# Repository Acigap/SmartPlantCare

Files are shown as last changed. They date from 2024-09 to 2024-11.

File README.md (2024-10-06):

# SmartPlantCare

**SmartPlantCare** is an automated plant watering system powered by ESP32 with a web interface for configuration and real-time monitoring, soil moisture sensors, SD card logging, and optional remote control through Blynk. The system uses **ESP32 T-Display-S3** for displaying data and **LILYGO® T-Display-S3 TF Shield** for SD card handling.

## Features
- Automatic irrigation based on soil moisture levels
- Hourly data logging to an SD card
- Real-time data display on **ESP32 T-Display-S3**
- Web interface for configuration and monitoring at `http://esp32sd.local`
- Remote control via Blynk app (optional)

## Components
- **ESP32 T-Display-S3**
- **LILYGO® T-Display-S3 TF Shield** (for SD card functionality)
- Soil Moisture Sensor
- Water Pump
- Relay Module
- Jumper wires
- Power supply (5V)
- Blynk App (optional)

## Hardware Setup

### 1. ESP32 T-Display-S3
- The **ESP32 T-Display-S3** includes a built-in display for real-time data such as soil moisture, watering status, and date/time.

### 2. LILYGO® T-Display-S3 TF Shield (SD Card Module)
- This shield is used for logging data to an SD card.
- **Wiring**:
  - MISO to GPIO 19
  - MOSI to GPIO 23
  - SCK to GPIO 18
  - CS to GPIO 5

### 3. Soil Moisture Sensor
- VCC to 3.3V (or 5V depending on the sensor)
- GND to GND
- Data to ESP32 analog pin (e.g., A0)

### 4. Water Pump & Relay Module
- Relay VCC to 5V
- Relay GND to GND
- IN to GPIO pin (e.g., GPIO 13)
- Water pump connected to relay (NO, COM)

## Software Setup

### 1. Install Required Libraries
- Open Arduino IDE and install the following libraries:
  - `TFT_eSPI` (for the **ESP32 T-Display-S3** screen)
  - `Blynk` (for remote control via Blynk)
  - `SD` (for handling SD card operations)
  - `ESPAsyncWebServer` (for the web interface)
  - `AsyncTCP` (for handling asynchronous web requests)

### 2. Clone the Repository
- Clone the repository and open `SmartPlantCare.ino` in Arduino IDE:
  ```bash
  git clone https://github.com/Acigap/SmartPlantCare.git
  ```

### 3. Web Interface Configuration
- The system includes a web interface for real-time monitoring and configuration. It allows you to:
  - View current soil moisture levels
  - Manually start or stop the water pump
  - Adjust soil moisture thresholds for automatic watering

**Web Interface Setup**:
- The ESP32 hosts a web server accessible at `http://esp32sd.local`.
- Ensure your ESP32 is connected to the same Wi-Fi network. Open a web browser and type `http://esp32sd.local` to access the web interface.

### 4. Blynk Setup (Optional)
- Install the Blynk app from the app store.
- Create a new project in the Blynk app and configure it to display soil moisture levels and control the water pump.

### 5. Upload the Code
- In Arduino IDE, select the correct board (`ESP32 T-Display-S3`) and port.
- Upload the code to your ESP32 board.

### 6. SD Card Logging
- The system logs data to a CSV file on the SD card every hour.
- The CSV log includes a timestamp, soil moisture level, and any watering actions.

### 7. Libraries Used

This project utilizes the following libraries, which can be found in the [T-Display-S3 GitHub repository](https://github.com/Xinyuan-LilyGO/T-Display-S3):

- **TFT_eSPI**: For controlling the TFT display on the ESP32 T-Display-S3.
- **Blynk**: For remote control and monitoring via the Blynk application.
- **SD**: For handling SD card operations to log data.
- **ESPAsyncWebServer**: To create a web server for real-time monitoring and configuration.
- **AsyncTCP**: To handle asynchronous TCP connections for the web server.

Ensure you install these libraries through the Arduino Library Manager or download them from their respective repositories.

## Usage

1. **Initial Setup**:
   - Place the soil moisture sensor in the plant’s soil.
   - Connect the water pump and ensure the SD card is inserted.

2. **Display**:
   - Real-time data, such as soil moisture percentage, system status, and last watering time, is displayed on the **ESP32 T-Display-S3**.

3. **Web Interface**:
   - Access the web interface by typing `http://esp32sd.local` into a browser.
   - Use the web interface to configure settings, monitor soil moisture levels, and manually control the water pump.

4. **Blynk** (optional):
   - Use the Blynk app to remotely monitor and control the system.

5. **SD Card**:
   - The system logs data on the SD card in CSV format.
   - You can download the logs from the web interface.

## Wiring Diagram
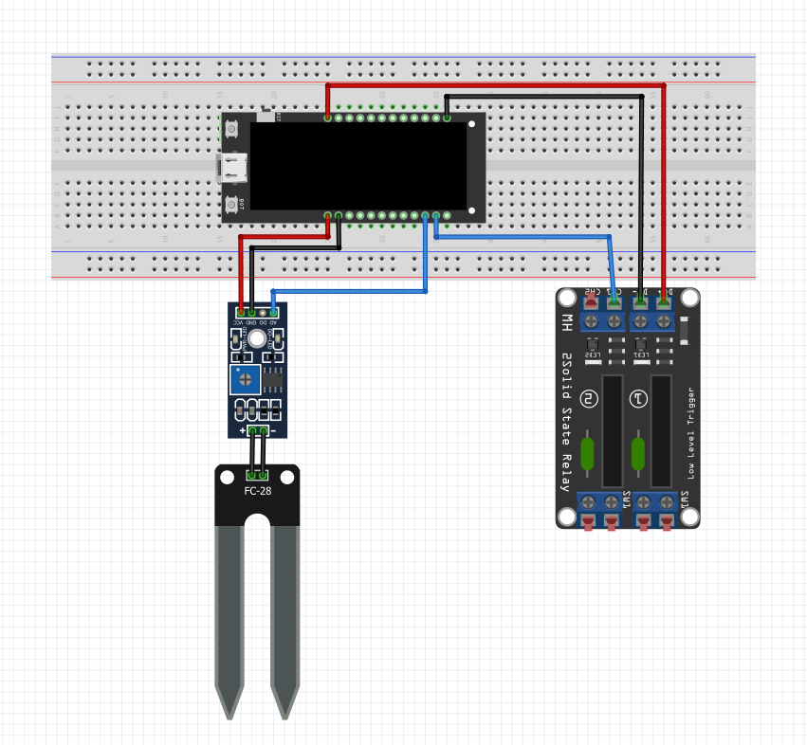
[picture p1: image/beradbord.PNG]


## Image 
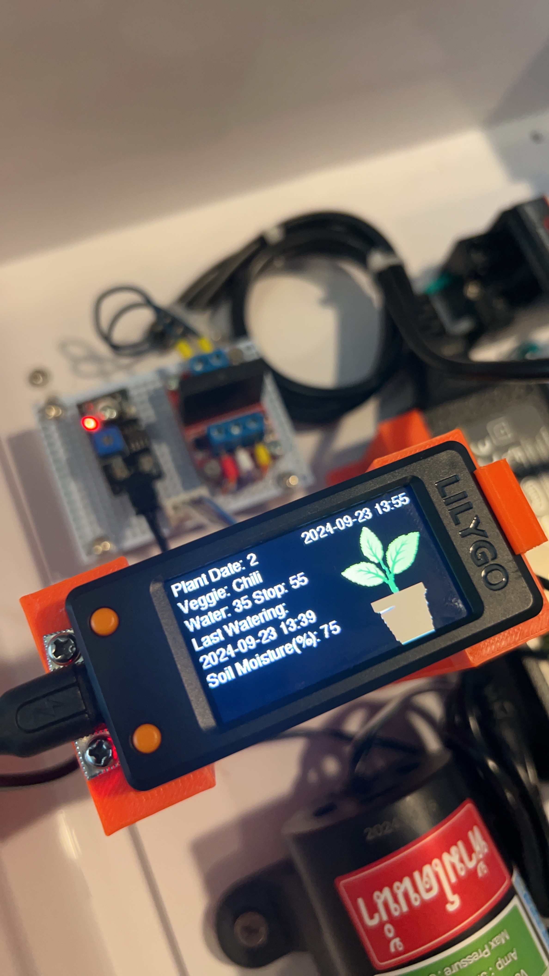
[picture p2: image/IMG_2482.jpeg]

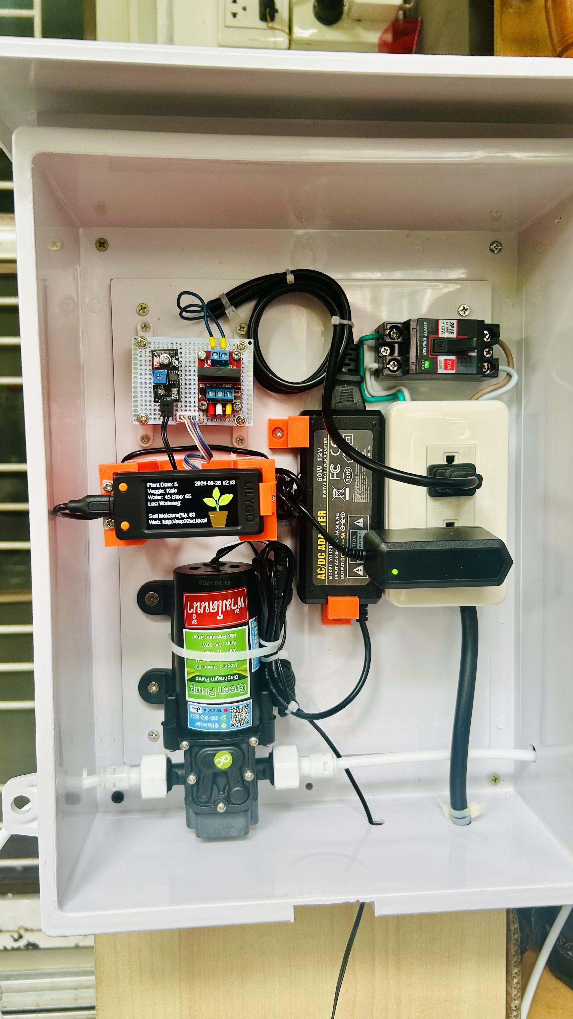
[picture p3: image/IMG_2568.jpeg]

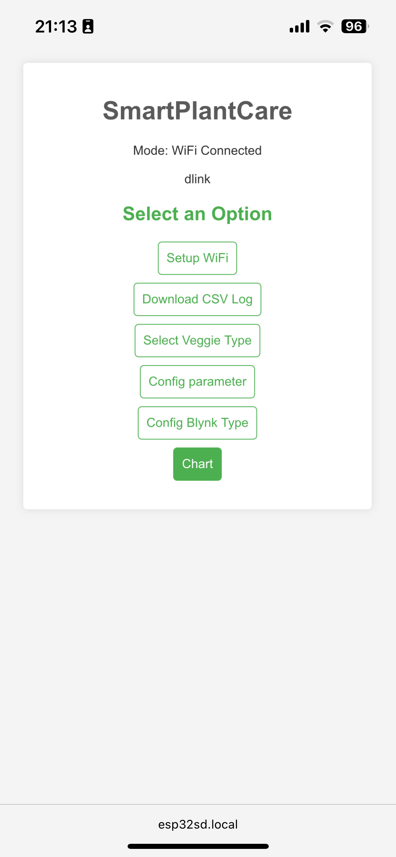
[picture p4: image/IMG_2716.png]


## Troubleshooting

- **Display not working**: Ensure the `TFT_eSPI` library is properly configured for **ESP32 T-Display-S3**.
- **Web interface not accessible**: Verify that the ESP32 is connected to Wi-Fi and try pinging `esp32sd.local` to check connectivity.
- **SD card issues**: Ensure the SD card is properly inserted and formatted correctly.

## License
This project is licensed under the MIT License.

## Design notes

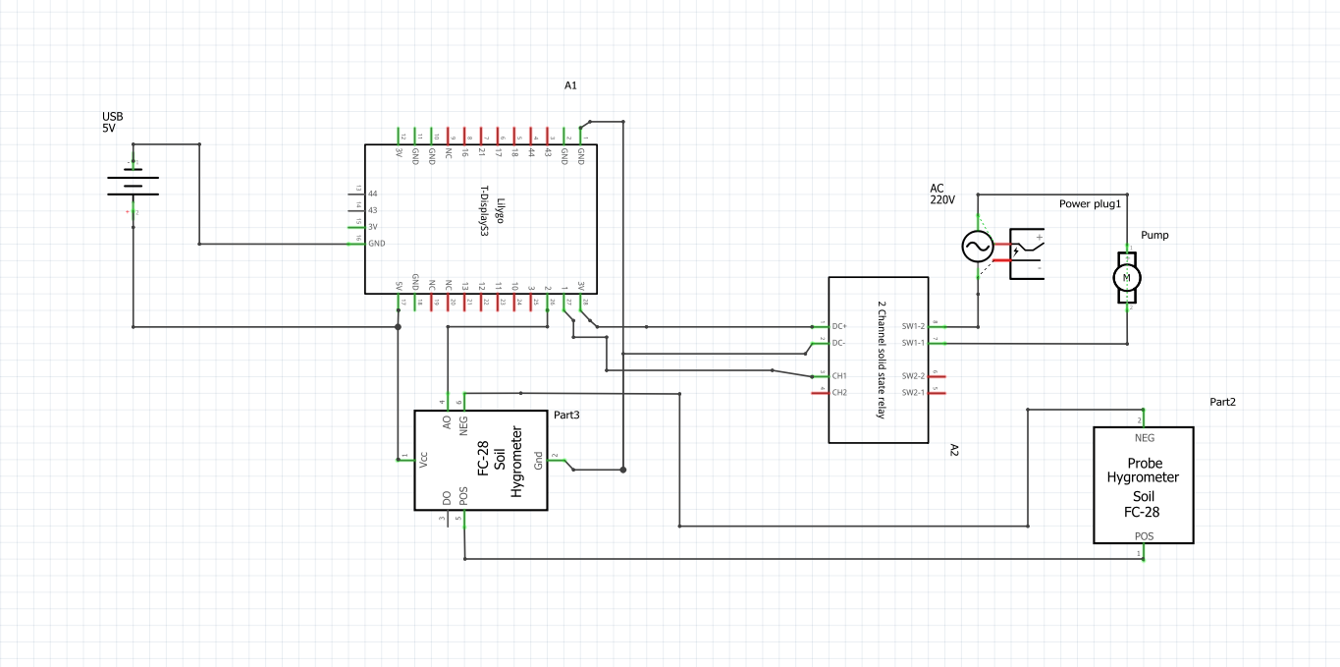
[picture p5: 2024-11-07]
image/schematicNoSD.PNG

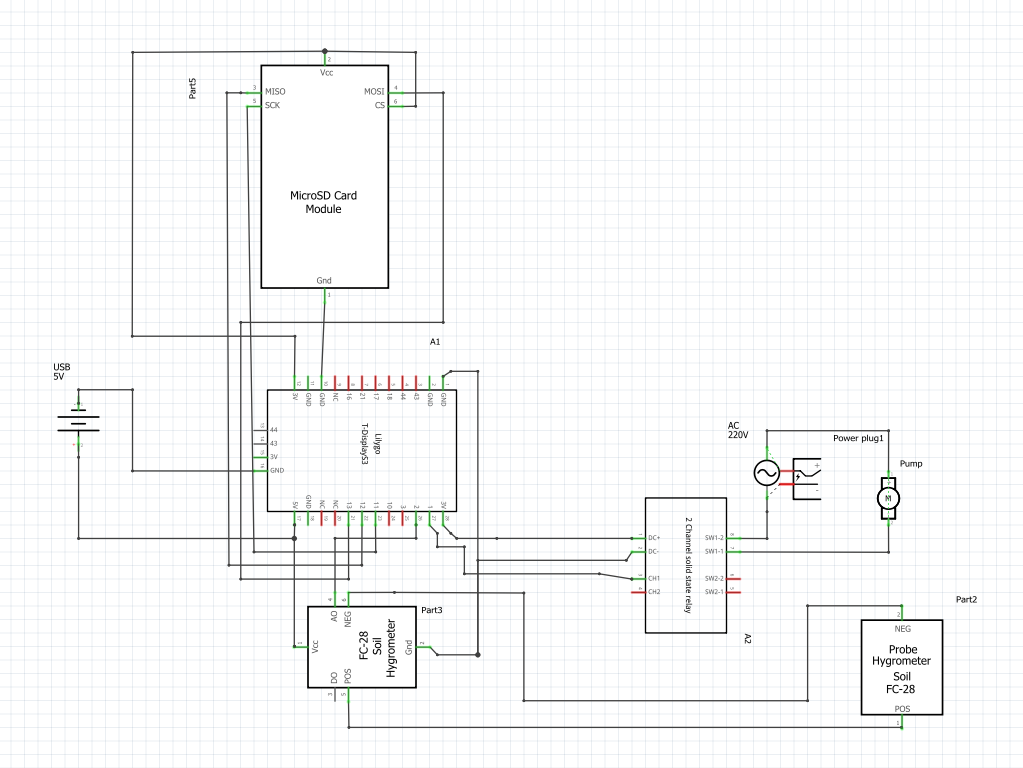
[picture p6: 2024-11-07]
image/schematic.PNG

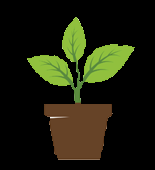
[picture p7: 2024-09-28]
image/plant.png

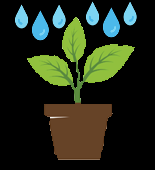
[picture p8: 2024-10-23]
image/watering.png

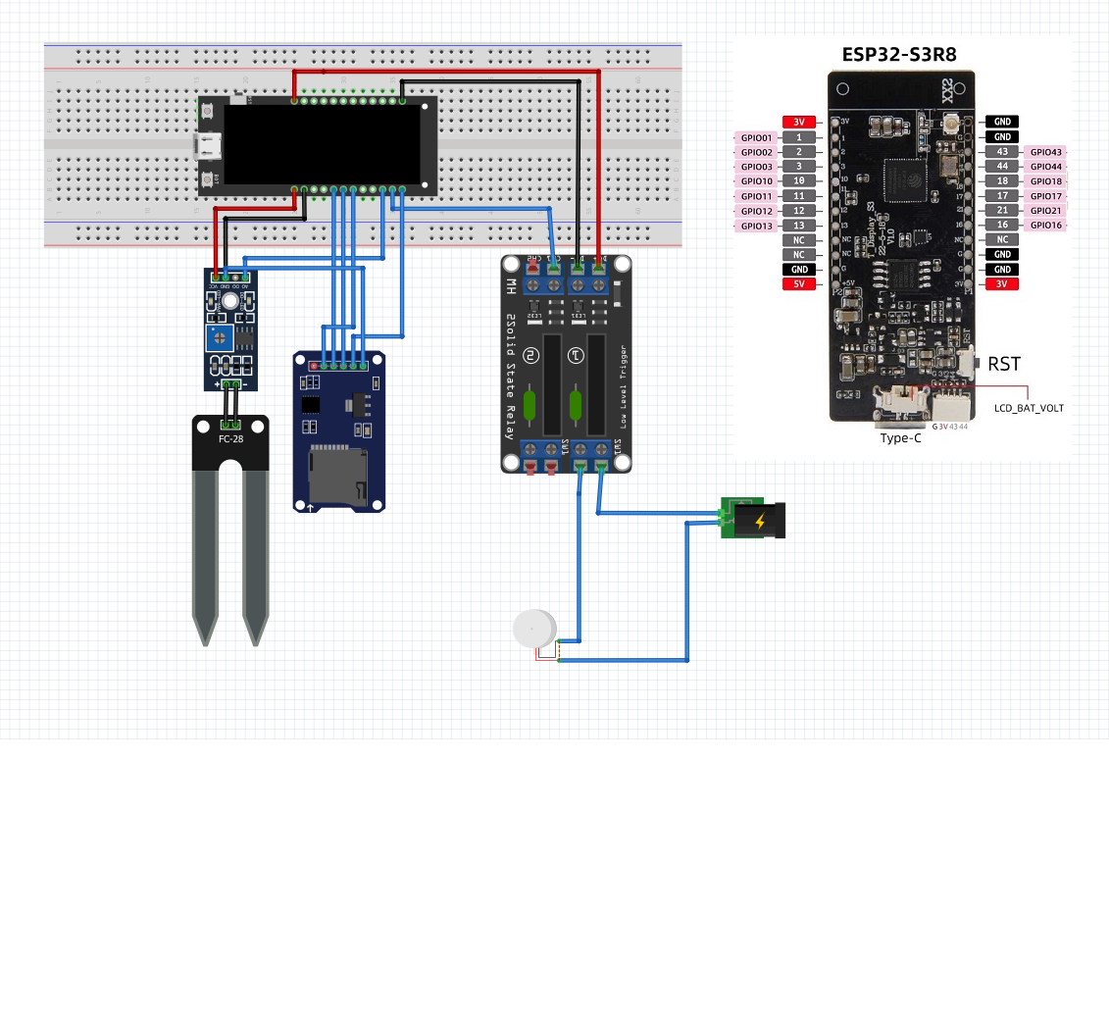
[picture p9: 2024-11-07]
image/beradbord2.PNG

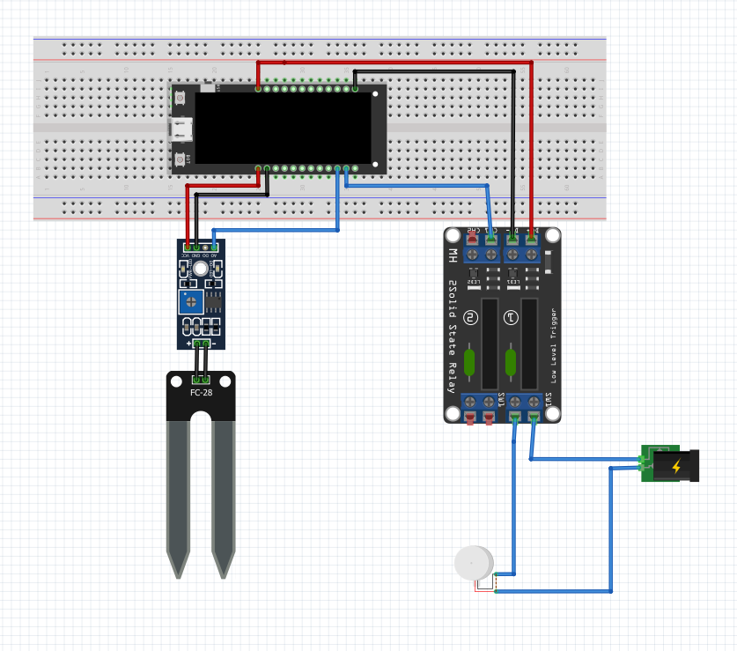
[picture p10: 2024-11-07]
image/beradbordNoSD.PNG

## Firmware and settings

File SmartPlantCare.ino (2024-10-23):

//This sketch is an SmartPlantCare
#define CUSTOM_TIMEZONE "CST-8" China time zone
#include <TFT_eSPI.h>  // สำหรับหน้าจอ T-display-s3
#include "hothead.h"
#include "watering.h"
#include <HTTPClient.h>
#include <WiFi.h>+
#include "Free_Fonts.h"     //free fonts must be included in the folder and quotes
#include "ControlSDCard.h"  // สำหรับจัดการเรื่อง SD Card และไฟล์
#include "BlynkData.h"
#include "ServerSD.h"
#include "smart_irrigation.h"
#include <ArduinoOTA.h>
#include "Wire.h"
#include "SHT31.h"

const char *hostSDServer = "esp32sd";
const char *ntpServer = "pool.ntp.org";
const long gmtOffset_sec = 25200;  // GMT +7
const int daylightOffset_sec = 0;
const char *startPlanTimeFilename = "/startPlanTime.txt";

#define RELAY_PIN 1          // พินของ relay
#define SOIL_MOISTURE_PIN 2  // ขาอนาล็อกที่ใช้ในการวัดความชื้นในดิน
#define BUTTOPN_PIN 14       // พินของ ปุ่มล่าง ของจอด้านหน้า

// I2C สำหรับวัดความชื้น SHT31
#define SHT31_ADDRESS   0x44
#define SDA_PIN 21  // ระบุพิน SDA เขียว
#define SCL_PIN 17  // ระบุพิน SCL เหลือง
SHT31 sht;
int sensorMin = 0;
int sensorMax = 0;
int soilMoisture = 0;

// เก็บ State กันการ set ค่าซ้ำ
bool buttonState = 0;
int switchPumState = 0;
bool waterPumpState = 0;
bool checkSoilStat = 0;

// ค่าใหม่สำหรับการควบคุมปั้มน้ำ
unsigned long pumpStartTime = 0; // เวลาที่เริ่มเปิดปั้มน้ำ
unsigned long pumpRunTime = 2 * 60 * 60 * 1000; // 2 ชั่วโมง
unsigned long pumpRestTime = 15 * 60 * 1000; // 15 นาที
bool isPumpCoolingDown = false; // ตัวแปรบันทึกสถานะการพักปั้มน้ำ

int dryValue = 4095;        // ค่าอนาล็อกเมื่อดินแห้ง (เซนเซอร์ไม่อยู่ในน้ำ)
int wetValue = 2400;        // ค่าอนาล็อกเมื่อดินเปียกเต็มที่ (เซนเซอร์อยู่ในน้ำ)
int displayCountDown = 30;  // สำหรับนับถอยหลังเพื่อปิดหน้าจอ
int buttonCountDown = 0;    // hold button count
String lastWatering = "";   // เวลารดน้ำล่าสุด

VeggieType veggie = KALE;  // เลือกชนิดของผัก (คะน้า)

static unsigned long lastLogTime = 0;      // loop check log time
static unsigned long lastDisplayTime = 0;  // loop check display time
static unsigned long lastReadDataTime = 0;  // loop check read data time
time_t plantingTime = 1680000000;          // เวลาในรูปแบบ epoch เมื่อเริ่มปลูก

TFT_eSPI tft = TFT_eSPI();
TFT_eSprite sprite = TFT_eSprite(&tft);
#define PIN_POWER_ON 15  //power enable pin for LCD and use battery
#define PIN_LCD_BL 38    // BackLight enable pin (see Dimming.txt)
String jsonBuffer;
struct tm timeinfo;


int calculateDaysPlanted() {
  time_t now = time(NULL);
  double secondsDiff = difftime(now, plantingTime);
  int daysPlanted = secondsDiff / (60 * 60 * 24);  // แปลงเป็นวัน
  return daysPlanted;
}

int readSoilMoisture() {
  int soilMoisturePercent = 0;
  uint16_t stat = sht.readStatus();
  // Serial.print(stat, HEX);

  if (stat != 0xFFFF) { // check SHT31 senser.
    sht.read(); 
    // Serial.print("\t");
    // Serial.print(sht.getTemperature(), 1);
    // Serial.print("\t");
    // Serial.println(sht.getHumidity(), 1);
    soilMoisturePercent = sht.getHumidity();
    virtualWriteV4(0);
    delay(150);
  } else { // if SHT31 not connect, So get soilMoisture from SOIL_MOISTURE_PIN
    //Serial.println("SHT31 error.");
    float soilMoisture = 0;
    int total = 0;
    int readings = 5;  // จำนวนครั้งที่ต้องการอ่านค่า
    // อ่านค่าจาก SOIL_MOISTURE_PIN จำนวน 3 ครั้งแล้วรวมค่า
    for (int i = 0; i < readings; i++) {
      total += analogRead(SOIL_MOISTURE_PIN);  // อ่านค่า SOIL_MOISTURE_PIN
      delay(30);                               // หน่วงเวลาเล็กน้อย (30 ms) ระหว่างการอ่านแต่ละครั้ง
    }
    // หาค่าเฉลี่ย
    soilMoisture = total / readings;
    // Serial.println("soilMoistureA0: ");
    // Serial.print(average);
    virtualWriteV4(soilMoisture);
    soilMoisturePercent = map(soilMoisture, wetValue, dryValue, 100, 0);
  }
 

  // ตรวจสอบว่าค่าความชื้นอยู่ในช่วงที่ถูกต้อง
  if (soilMoisturePercent >= 100) {
    soilMoisturePercent = 100;
  } else if (soilMoisturePercent <= 0) {
    soilMoisturePercent = 0;
  }
  return soilMoisturePercent;
}

void logSDd(const char *action, const char *value) {
  String data = getCurrentDateTime() + String(",") + String(action) + String(",") + String(value) + String("\n");
  appendFile(csvFilename, data.c_str());
}

void controlWaterPump(bool state, int moisture, bool isManual) {
  if (waterPumpState == state) {
    return;
  }
  logsSoilMoisture(moisture);
  waterPumpState = state;
  displayCountDown = 30;
  char *action = "ControlPump";
  if (isManual) {
    action = "ManualPump";
  } else {
    virtualWriteV0(state);
  }

  if (state) {
    lastWatering = getCurrentDateTime();
    digitalWrite(RELAY_PIN, LOW);  // เปิดปั้มน้ำ
    logSDd(action, "Start");
    pumpStartTime = millis(); // บันทึกเวลาที่เริ่มเปิดปั้มน้ำ
    isPumpCoolingDown = false; // รีเซ็ตสถานะการพัก
    Serial.println("**Open Pump**");
  } else {
    digitalWrite(RELAY_PIN, HIGH);  // ปิดปั้มน้ำ
    logSDd(action, "Stop");
    Serial.println("**Close Pump**");
  }

  lastDisplayTime = 0; // Show info now.
  // Serial.println(String(action) + "" + String(state));
}

void displayInfo(int moisture, int days, String strLastWatering) {
  tft.fillScreen(TFT_BLACK);
  if(waterPumpState) {
    tft.pushImage(165, 10, 155, 170, watering);
  } else {
    tft.pushImage(165, 10, 155, 170, hothead);
  }

  int threshold, stop;
  getMoistureRange(veggie, threshold, stop, sensorMin, sensorMax);

  tft.setTextColor(TFT_WHITE);
  tft.setFreeFont(FSS9);
  tft.setCursor(165, 18);
  tft.println(getCurrentDateTime());
  tft.setCursor(0, 18);
  tft.println("Plant Date: " + String(days));
  tft.println("Veggie: " + String(veggieToString(veggie)));
  tft.println("Water: " + String(threshold) + " Stop: " + String(stop));
  tft.println("Last Watering: ");
  tft.println(strLastWatering);
  tft.println("Soil Moisture(%): " + String(moisture));
  tft.println("Web: http://" + String(hostSDServer) + ".local");
  if(isConnected() == false) {
    tft.setTextColor(TFT_RED);
  } else {
    tft.setTextColor(TFT_GREEN);
  }
  tft.setFreeFont(FSB9);
  tft.setCursor(270, 160);
  tft.println("Blynk");
}

void checkSoilMoisture(int moisture) {
  virtualWriteV2(moisture);
  // ตรวจสอบการควบคุมปั๊มน้ำ
  bool isPumpOn = checkPumpControl(veggie, moisture, sensorMin, sensorMax);
  if (checkSoilStat == isPumpOn) {
    return;
  }
  checkSoilStat = isPumpOn;
  controlWaterPump(isPumpOn, moisture, false);
}

// ฟังก์ชันสำหรับดึงและแสดงวันที่และเวลาปัจจุบันในรูปแบบ yyyy-mm-dd HH:mm
String getCurrentDateTime() {
  // ดึงเวลาปัจจุบันในรูปแบบ epoch time
  time_t now = time(NULL);

  // แปลงเป็นโครงสร้างเวลามนุษย์ (local time)
  struct tm *timeinfo = localtime(&now);

  // ดึงข้อมูลปี เดือน วัน ชั่วโมง และนาที
  int year = timeinfo->tm_year + 1900;  // ปี (tm_year นับจาก 1900)
  int month = timeinfo->tm_mon + 1;     // เดือน (tm_mon เริ่มจาก 0 = มกราคม)
  int day = timeinfo->tm_mday;          // วันของเดือน
  int hour = timeinfo->tm_hour;         // ชั่วโมง
  int minute = timeinfo->tm_min;        // นาที

  // แปลงวันที่และเวลาเป็น String ในรูปแบบ yyyy-mm-dd HH:mm
  char dateTimeBuffer[20];
  snprintf(dateTimeBuffer, sizeof(dateTimeBuffer), "%04d-%02d-%02d %02d:%02d", year, month, day, hour, minute);
  // Serial.println(&timeinfo, "%A, %B %d %Y %H:%M:%S");
  return String(dateTimeBuffer); 
}

void initWiFi() {
  Serial.println("    Start func init WiFi");
  tft.setFreeFont(FSS9);
  tft.fillRect(10, 32, 130, 25, TFT_BLACK);  //horiz, vert
  tft.setTextColor(TFT_RED);
  tft.setCursor(30, 50);
  tft.println("init WiFi");
  Serial.println("init WiFi");
  delay(500);
  WiFi.mode(WIFI_STA);

  connectToWiFi();

  int attempt = 0;
  const int max_attempts = 20;

  // ลูปพยายามเชื่อมต่อ WiFi
  while (WiFi.status() != WL_CONNECTED && attempt < max_attempts) {
    delay(500);
    Serial.print(".");
    attempt++;
  }

  if (WiFi.status() == WL_CONNECTED) {
    Serial.println("WL  CONNECTED in initWiFi");
    tft.fillRect(10, 32, 130, 25, TFT_BLACK);  //horiz, vert
    tft.setTextColor(TFT_GREEN);
    tft.setCursor(30, 50);
    tft.println("connected");
    tft.println("LocalIP: " + WiFi.localIP());
    delay(1000);
  } else {
    Serial.println("WL not CONNECTED in initWiFi");
    tft.fillRect(10, 32, 130, 25, TFT_BLACK);  //horiz, vert
    tft.setTextColor(TFT_RED);
    tft.setCursor(30, 50);
    tft.println("No WiFi");
  }
  delay(500);
  Serial.println("");
  Serial.print("Connected to WiFi network with IP Address: ");
  Serial.println(WiFi.localIP());
}

// ฟังก์ชันที่ทำงานเมื่อข้อมูลมีการเปลี่ยนแปลง
void onStartAPMode(String ip, String ap, String pwd) {
  tft.fillRect(10, 32, 130, 25, TFT_BLACK);  //horiz, vert
  tft.setTextColor(TFT_GREEN);
  tft.setCursor(30, 50);
  tft.println("Start AP Mode");
  tft.println("AP: " + ap);
  tft.println("PWD: " + pwd);
  tft.println("Server IP: " + ip);
}

void logsSoilMoisture(int soilMoisture) {
  char buf[4];
  itoa(soilMoisture, buf, 10);
  logSDd("SoilMoisture", buf);
}

void createLogFile() {
  String str = readFileToString(csvFilename);
  if (str.isEmpty()) {
    Serial.println("writeFile: " + String(csvFilename));
    writeFile(csvFilename, "time, action, value\n");
  }
}

void checkPumpCoolingDown() {
  unsigned long currentMillis = millis();
  if (isPumpCoolingDown) {
    if (currentMillis - pumpStartTime >= pumpRestTime) {
      isPumpCoolingDown = false; // หมดเวลา พักปั้มน้ำ
      if (waterPumpState) {
        digitalWrite(RELAY_PIN, LOW); // เปิดปั้มน้ำใหม่
        pumpStartTime = millis(); // บันทึกเวลาที่เริ่มเปิดปั้มน้ำ
      }
    }
  } else if (waterPumpState) {
    if (currentMillis - pumpStartTime >= pumpRunTime) {
      digitalWrite(RELAY_PIN, HIGH);// ปิดปั้มน้ำเมื่อถึงเวลา
      pumpStartTime = currentMillis; // เริ่มพัก
      isPumpCoolingDown = true; // กำลังพัก
    }
  }
}

void setupSHT31() {
  Serial.println("setupSHT31");
  Wire.begin(SDA_PIN, SCL_PIN);
  sht.begin();
  Wire.setClock(100000);

  uint16_t stat = sht.readStatus();
  Serial.print(stat, HEX);
  Serial.println();
}

void setUpOTA() {
  Serial.println("setUpOTA");
  // เริ่มต้นการทำงาน OTA
  ArduinoOTA.onStart([]() {
    String type;
    if (ArduinoOTA.getCommand() == U_FLASH) {
      type = "sketch";
    } else {  // U_SPIFFS
      type = "filesystem";
    }
    // NOTE: หากใช้ SPIFFS ให้ปิด SPIFFS ก่อนที่จะเริ่มการอัปเดต
    Serial.println("Start updating " + type);
  });
  ArduinoOTA.onEnd([]() {
    Serial.println("\nEnd");
  });
  ArduinoOTA.onProgress([](unsigned int progress, unsigned int total) {
    Serial.printf("Progress: %u%%\r", (progress / (total / 100)));
  });
  ArduinoOTA.onError([](ota_error_t error) {
    Serial.printf("Error[%u]: ", error);
    if (error == OTA_AUTH_ERROR) {
      Serial.println("Auth Failed");
    } else if (error == OTA_BEGIN_ERROR) {
      Serial.println("Begin Failed");
    } else if (error == OTA_CONNECT_ERROR) {
      Serial.println("Connect Failed");
    } else if (error == OTA_RECEIVE_ERROR) {
      Serial.println("Receive Failed");
    } else if (error == OTA_END_ERROR) {
      Serial.println("End Failed");
    }
  });

  ArduinoOTA.setHostname(hostSDServer);
  ArduinoOTA.begin();
}

void setup() {
  pinMode(RELAY_PIN, OUTPUT);  // ตั้งพินสำหรับ relay เป็น output
  pinMode(BUTTOPN_PIN, INPUT);
  digitalWrite(RELAY_PIN, HIGH);  // ปิด relay ตอนเริ่มต้น
  pinMode(PIN_POWER_ON, OUTPUT);  //enables the LCD and to run on battery
  pinMode(PIN_LCD_BL, OUTPUT);    //triggers the LCD backlight
  digitalWrite(PIN_POWER_ON, HIGH);
  digitalWrite(PIN_LCD_BL, HIGH);
  configTime(gmtOffset_sec, daylightOffset_sec, ntpServer);
  Serial.begin(115200);  // be sure to set USB CDC On Boot: "Enabled"

  setupSDCard();

  tft.fillRect(0, 165, 130, 60, TFT_CYAN);  //horiz, vert
  tft.setFreeFont(FSS9);
  tft.setTextColor(TFT_RED);
  tft.setCursor(30, 50);
  tft.print("in setup");
  tft.init();
  Serial.println("          in setup");
  Serial.println("  ");
  tft.setRotation(3);
  tft.setSwapBytes(true);
  tft.fillScreen(TFT_BLACK);  //horiz / vert<> position/dimension
  tft.pushImage(165, 0, 155, 170, hothead);
  tft.setTextColor(TFT_GREEN);
  tft.setFreeFont(FSB12);
  tft.setCursor(5, 25);
  tft.println("SmartPlantCare");

  initWiFi();                                  // ตั้งค่า wifi
  setUpOTA();
  setupBlynk();                                // ตั้งค่า Blynk lib
  setupServerSD(hostSDServer, onStartAPMode);  // ตั้งค่า web server

  Serial.println("Setup log file.");
  // log
  createLogFile();
  logSDd("Esp32Start", "initOK");
  String startStr = readFileToString(startPlanTimeFilename);
  if (startStr.isEmpty()) {
     plantingTime = time(NULL);
  } else {
    plantingTime = startStr.toInt();
    Serial.println("startStr: " + startStr);
    Serial.println(plantingTime);
  }
  
  Serial.println("Read preferences and setup ConfigParameter");
  preferences.begin("VeggieType", false);
  int32_t veggieTypeInt = preferences.getInt("selectedVeggie", 5);
  // ดึงค่าจาก Preferences
  veggie = static_cast<VeggieType>(veggieTypeInt);  // แปลงไปเป็น VeggieType
  preferences.end();
  Serial.println("VeggieType: " + String(veggieTypeInt));

  preferences.begin("ConfigParameter", false);
  wetValue = preferences.getInt("selectedWet", wetValue);  // ค่าเริ่มต้นคือ wetValue
  dryValue = preferences.getInt("selectedDry", dryValue);  // ค่าเริ่มต้นคือ dryValue
  pumpRunTime = preferences.getLong("pumpRunTime", pumpRunTime);  // ค่าเริ่มต้นคือ 0
  pumpRestTime = preferences.getLong("coolingDownTime", pumpRunTime);  // ค่าเริ่มต้นคือ 0
  preferences.end();
  // Serial.println("WetValue: " + String(wetValue));
  // Serial.println("DryValue: " + String(dryValue));
  setupSHT31();
  virtualWriteV0(0); // Send 0 when fist open
  Serial.println("**************** SetUp End ****************");
}

void loop() {
  ArduinoOTA.handle();                    // ตรวจสอบการเชื่อมต่อ OTA
  loopServerSD();
  loopBlynk();

  if (millis() - lastReadDataTime >= 500) {  // 500 ms = 0.5 วินาที
    sensorMin = getSensorMin();
    sensorMax = getSensorMax(); 
    soilMoisture = readSoilMoisture();  // อ่านค่าความชื้นในดิน
    checkSoilMoisture(soilMoisture);        // ตรวจสอบความชื้นในดินและสั่งรดน้ำ
    lastReadDataTime = millis();  
  }
  if (millis() - lastDisplayTime >= 1000) {  // 1000 ms = 1 วินาที
    // แสดงข้อมูลบนหน้าจอ
    int daysPlanted = calculateDaysPlanted();              // คำนวณจำนวนวันที่ปลูกมาแล้ว
    displayInfo(soilMoisture, daysPlanted, lastWatering);  // อัปเดตข้อมูลบนหน้าจอ
    lastDisplayTime = millis();                            // อัปเดตเวลาล่าสุดที่แสดงจอ
    displayCountDown--;
    if (displayCountDown < 0) { displayCountDown = 0; }
  }
  if (millis() - lastLogTime >= 300000) {  // 1000 = 1sec. * 60 * 5  = 300,000 sec. (5 นาที)
    logsSoilMoisture(soilMoisture);
    lastLogTime = millis();  // อัปเดตเวลาล่าสุดที่บันทึกข้อมูล
  }

  // Check switchPum from Blynk server
  int switchPumData = getSwitchPum();
  if (switchPumState != switchPumData) {
    controlWaterPump(switchPumData, soilMoisture, true);
    switchPumState = switchPumData;
  }

  checkPumpCoolingDown();

  buttonState = digitalRead(BUTTOPN_PIN);
  // check if the pushbutton is pressed. If it is, the buttonState is HIGH:
  if (buttonState == LOW) {
    displayCountDown = 30;
    buttonCountDown--;
    if (buttonCountDown < 0) {
      plantingTime = time(NULL);
      char temp[10];
      ltoa(plantingTime, temp, 10);
      writeFile(startPlanTimeFilename, temp);
      buttonCountDown = 10;
      Serial.println(plantingTime);
      Serial.println(temp);

      // เคลียร์ log file โดยการเปลียนชื่อเป็น timestamp แล้วสร้างใหม่
      String filename = "/" + String(temp) + ".csv";
      renameFile(csvFilename, filename.c_str());
      delay(200);
      createLogFile();

      tft.fillScreen(TFT_BLACK);
      tft.pushImage(165, 0, 155, 170, hothead);
      tft.setCursor(10, 50);
      tft.setFreeFont(FSS9);
      tft.setTextColor(TFT_GREEN);
      tft.println("Set start plant finish..");
      delay(3000);
    } else {
      Serial.println(buttonCountDown);
      if (buttonCountDown <= 9) {  // ไม่แสดงค่านับถอนหลัง้ากดไปแค่ 1-2 วินาที
        tft.fillRect(0, 140, 165, 175, TFT_BLACK);  //horiz, vert
        tft.setCursor(0, 155);
        tft.setTextColor(TFT_BLUE);
        tft.println("Set start plant <-- " + String(buttonCountDown));
      }
    }
    delay(500);
  } else {
    buttonCountDown = 10;
  }

  if (displayCountDown <= 0) {
    // turn LED off:
    digitalWrite(PIN_LCD_BL, LOW);
  } else {
    // turn LED on:
    digitalWrite(PIN_LCD_BL, HIGH);
  }
  delay(100);
}

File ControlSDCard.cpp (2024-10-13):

#include "FS.h"  // สำหรับจัดการไฟล์
#include "SD_MMC.h" // สำหรับจัดการ SD card
#include "ControlSDCard.h"


String readFileToString(const char *path)
{
  File file = SD_MMC.open(path);
  if (!file) {
    Serial.println("Failed to open file for reading");
    return "";
  }
  
  String s = "";
  while (file.available()){
    s +=  (char)file.read();
  }
  return s;
}

void writeFile(const char *path, const char *message)
{
  Serial.printf("Writing file: %s\n", path);

  File file = SD_MMC.open(path, FILE_WRITE);
  if (!file) {
    Serial.println("Failed to open file for writing");
    return;
  }
  if (file.print(message)) {
    Serial.println("File written");
  } else {
    Serial.println("Write failed");
  }
}

void appendFile(const char *path, const char *message)
{
  //Serial.printf("Appending to file: %s\n", path);

  File file = SD_MMC.open(path, FILE_APPEND);
  if (!file) {
    Serial.println("Failed to open file for Appending");
    return;
  }
  if (file.print(message)) {
    //Serial.println("Message appended");
  } else {
    Serial.println("Append failed");
  }
}

void renameFile(const char *path1, const char *path2)
{
  Serial.printf("Renaming file %s to %s\n", path1, path2);
  if (SD_MMC.rename(path1, path2)) {
    Serial.println("File renamed");
  } else {
    Serial.println("Rename failed");
  }
}

void setupSDCard() {
  SD_MMC.setPins(PIN_SD_CLK, PIN_SD_CMD, PIN_SD_D0);
  if (!SD_MMC.begin("/sdcard", true, true)) {
    Serial.println("Card Mount Failed");
    return;
  }
  uint8_t cardType = SD_MMC.cardType();

  if (cardType == CARD_NONE) {
    Serial.println("No SD_MMC card attached");
    return;
  }

  Serial.print("SD_MMC Card Type: ");
  if (cardType == CARD_MMC) {
    Serial.println("MMC");
  } else if (cardType == CARD_SD) {
    Serial.println("SDSC");
  } else if (cardType == CARD_SDHC) {
    Serial.println("SDHC");
  } else {
    Serial.println("UNKNOWN");
  }

  uint64_t cardSize = SD_MMC.cardSize() / (1024 * 1024);
  Serial.printf("SD_MMC Card Size: %lluMB\n", cardSize);
  Serial.printf("Total space: %lluMB\n", SD_MMC.totalBytes() / (1024 * 1024));
  Serial.printf("Used space: %lluMB\n", SD_MMC.usedBytes() / (1024 * 1024));
}

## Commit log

2024-09-18 [bug] Fixed control pump when send from blynk
    [SmartPlantCare.ino]
2024-09-18 [bug] Update switchPum when controlWaterPump changed
    [BlynkData.cpp]
2024-09-20 [bug] Fixed read file from SD and add logic to handle set start plant day.
    [ControlSDCard.cpp, SmartPlantCare.ino]
2024-09-22 [bug] Fixed status pump wrong when manual start by blynk and fixed check time wrong.
    [BlynkData.cpp, ControlSDCard.cpp, SmartPlantCare.ino]
2024-09-23 [bug] Fixed web wifi setup missing
    [ServerSD.cpp]
2024-09-23 [bug] Fixed check ssid mode wrong
    [ServerSD.cpp]
2024-09-27 [add] Create logic for check pump run time and cooldown pump when run over limit and create seting limit value on mini web
2024-10-03 [add] Create Graph web from csv
    [log.csv]
2024-10-04 [bug] Fixed wrong status pump point and wrong name.
2024-10-06 [add] image beradboad and edit readme
    [SmartPlantCare.fzz]
2024-10-06 [bug] Fixed code blynk
    [BlynkData.cpp]
2024-10-13 [add] Can set min max sensor when set veggie type defalt
2024-10-13 [bug] add manual web
    [ServerSD.cpp]
2024-10-13 [bug] Fixed datetime get empty and keep data when set up from blynk
    [BlynkData.cpp, ControlSDCard.cpp, ServerSD.cpp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]
2024-10-23 [bug] Fixed set up OTA after wifi connected
    [SmartPlantCare.ino]
2024-10-23 [bug] Fixed OTA host fail
    [ServerSD.cpp, SmartPlantCare.ino]
2024-10-30 [bug] Fixed when has new esp32 and first setup is not work it restart away
    [BlynkData.cpp, ServerSD.cpp]
2024-11-07 [add] Add image and documents
    [SmartPlantCare.fzz, SmartPlantCareNoSD.fzz]
